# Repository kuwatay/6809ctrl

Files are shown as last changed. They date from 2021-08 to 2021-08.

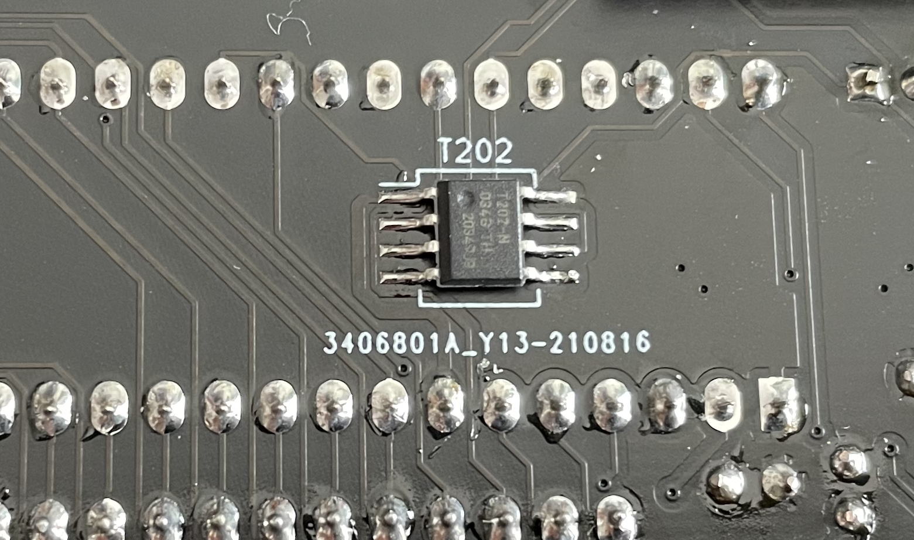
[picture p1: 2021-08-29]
hardware/6809E-CLOCK/clock-gen-t202.jpg

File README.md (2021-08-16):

# 6809ctrl (UNDER DEVELOPMENT)
AVR-based supervisor for a 6809E microcomputer based on z80ctrl https://github.com/jblang/z80ctrl

* Arduino Shield style hardware (6809Ectrl-mega)
* Flexible MIT-licensed firmware inhelited from z80ctrl

# Documentation

## Application

## Hardware note
https://github.com/kuwatay/6809ctrl/tree/main/hardware
## Supervisor sample session

## DMA handling

## MIT license
Permission is hereby granted, free of charge, to any person obtaining a copy of this software and associated documentation files (the "Software"), to deal in the Software without restriction, including without limitation the rights to use, copy, modify, merge, publish, distribute, sublicense, and/or sell copies of the Software, and to permit persons to whom the Software is furnished to do so, subject to the following conditions:

The above copyright notice and this permission notice shall be included in all copies or substantial portions of the Software.

THE SOFTWARE IS PROVIDED "AS IS", WITHOUT WARRANTY OF ANY KIND, EXPRESS OR IMPLIED, INCLUDING BUT NOT LIMITED TO THE WARRANTIES OF MERCHANTABILITY, FITNESS FOR A PARTICULAR PURPOSE AND NONINFRINGEMENT. IN NO EVENT SHALL THE AUTHORS OR COPYRIGHT HOLDERS BE LIABLE FOR ANY CLAIM, DAMAGES OR OTHER LIABILITY, WHETHER IN AN ACTION OF CONTRACT, TORT OR OTHERWISE, ARISING FROM, OUT OF OR IN CONNECTION WITH THE SOFTWARE OR THE USE OR OTHER DEALINGS IN THE SOFTWARE.

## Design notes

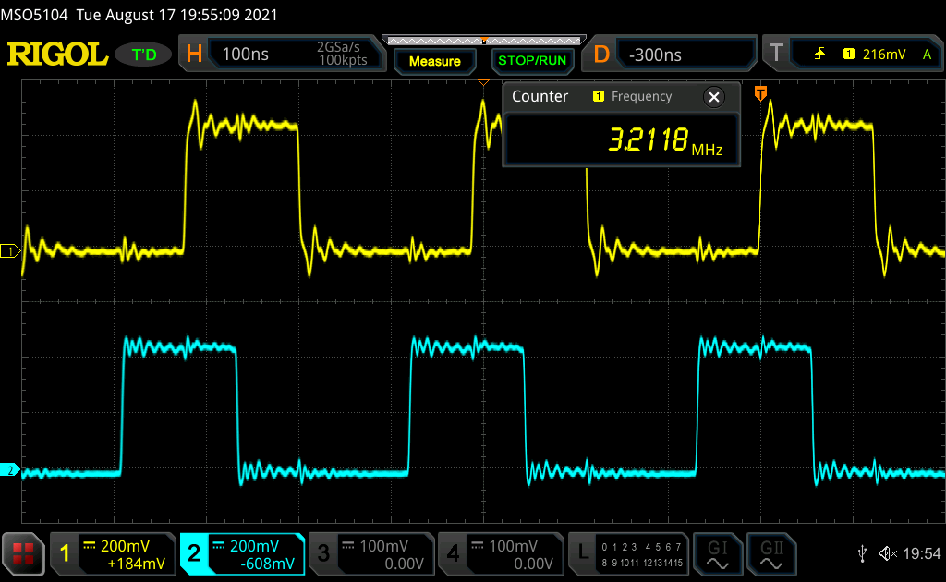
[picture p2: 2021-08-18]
hardware/6809E-CLOCK/3MHz-clock.png

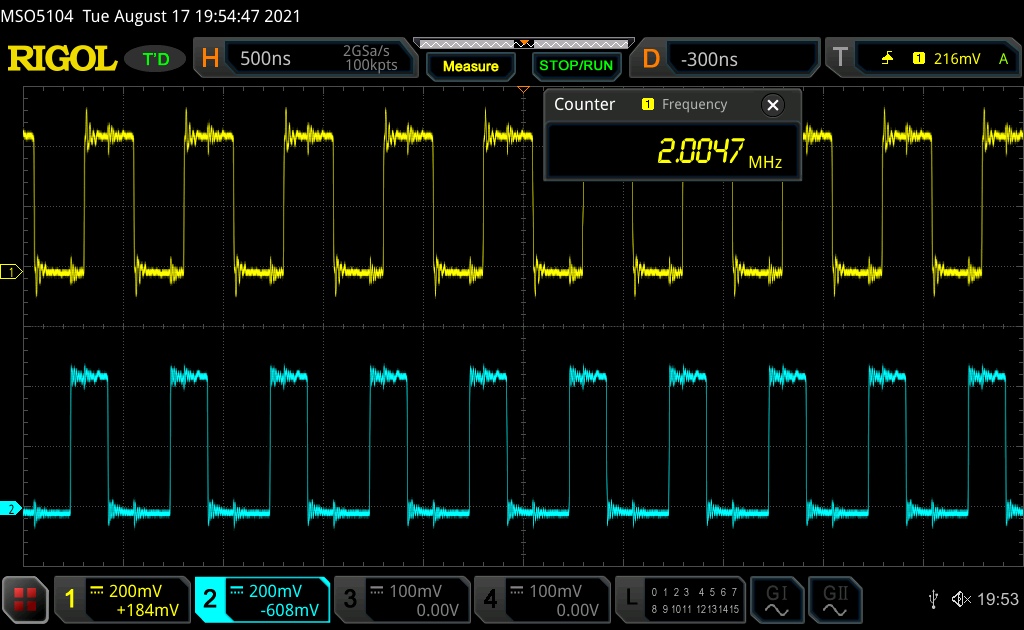
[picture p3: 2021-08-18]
hardware/6809E-CLOCK/2MHz-clock.png

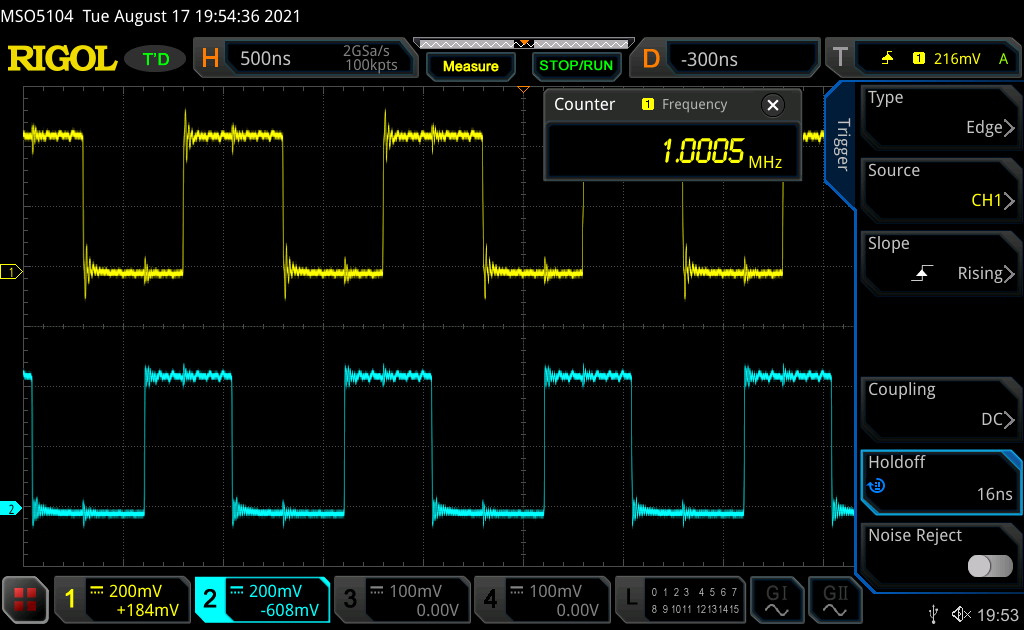
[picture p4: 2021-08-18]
hardware/6809E-CLOCK/1MHz-clock.png

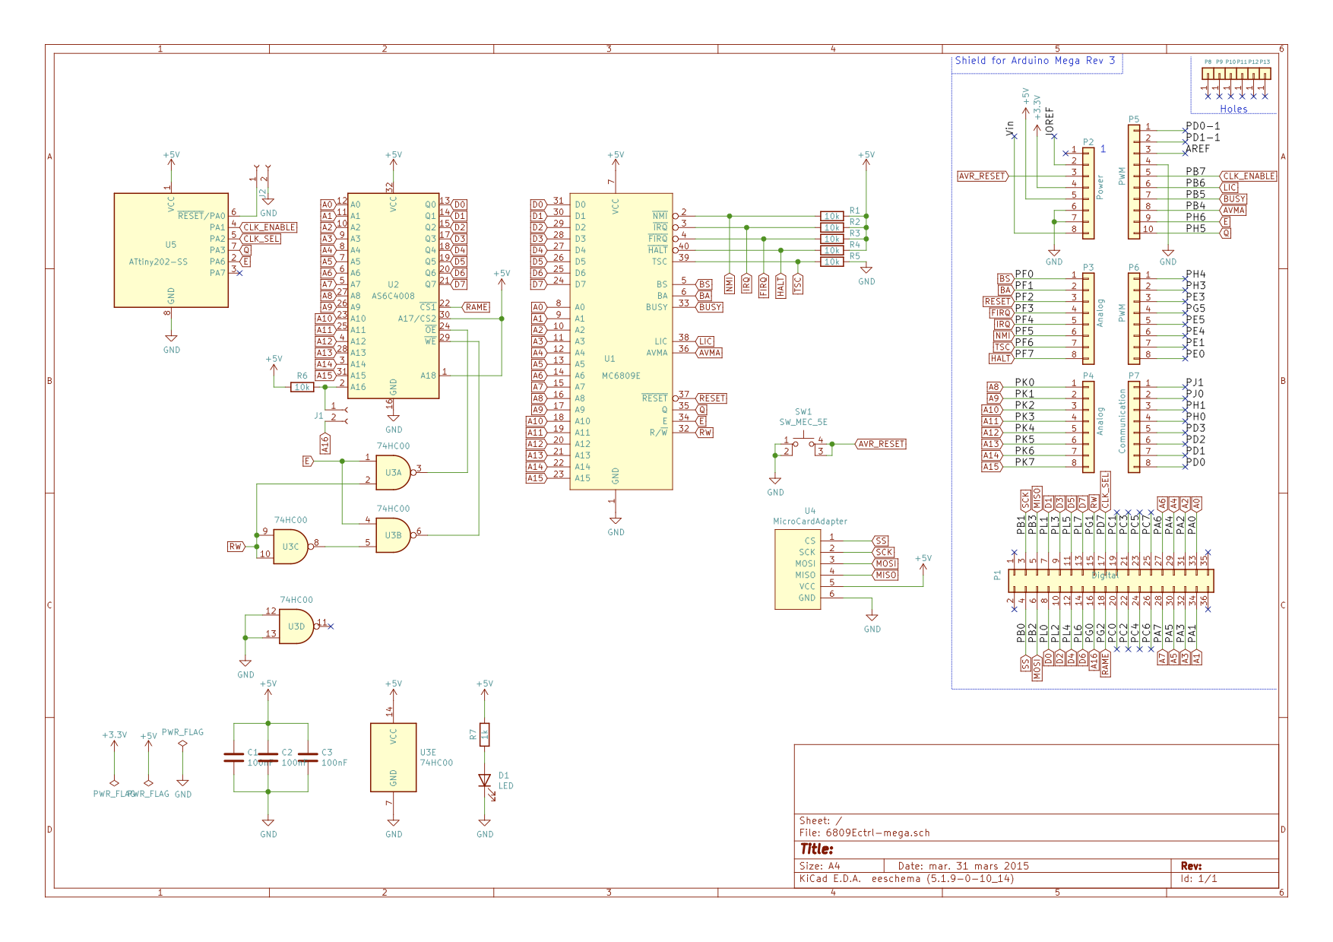
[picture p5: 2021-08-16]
hardware/6809E-mega-schematic.png

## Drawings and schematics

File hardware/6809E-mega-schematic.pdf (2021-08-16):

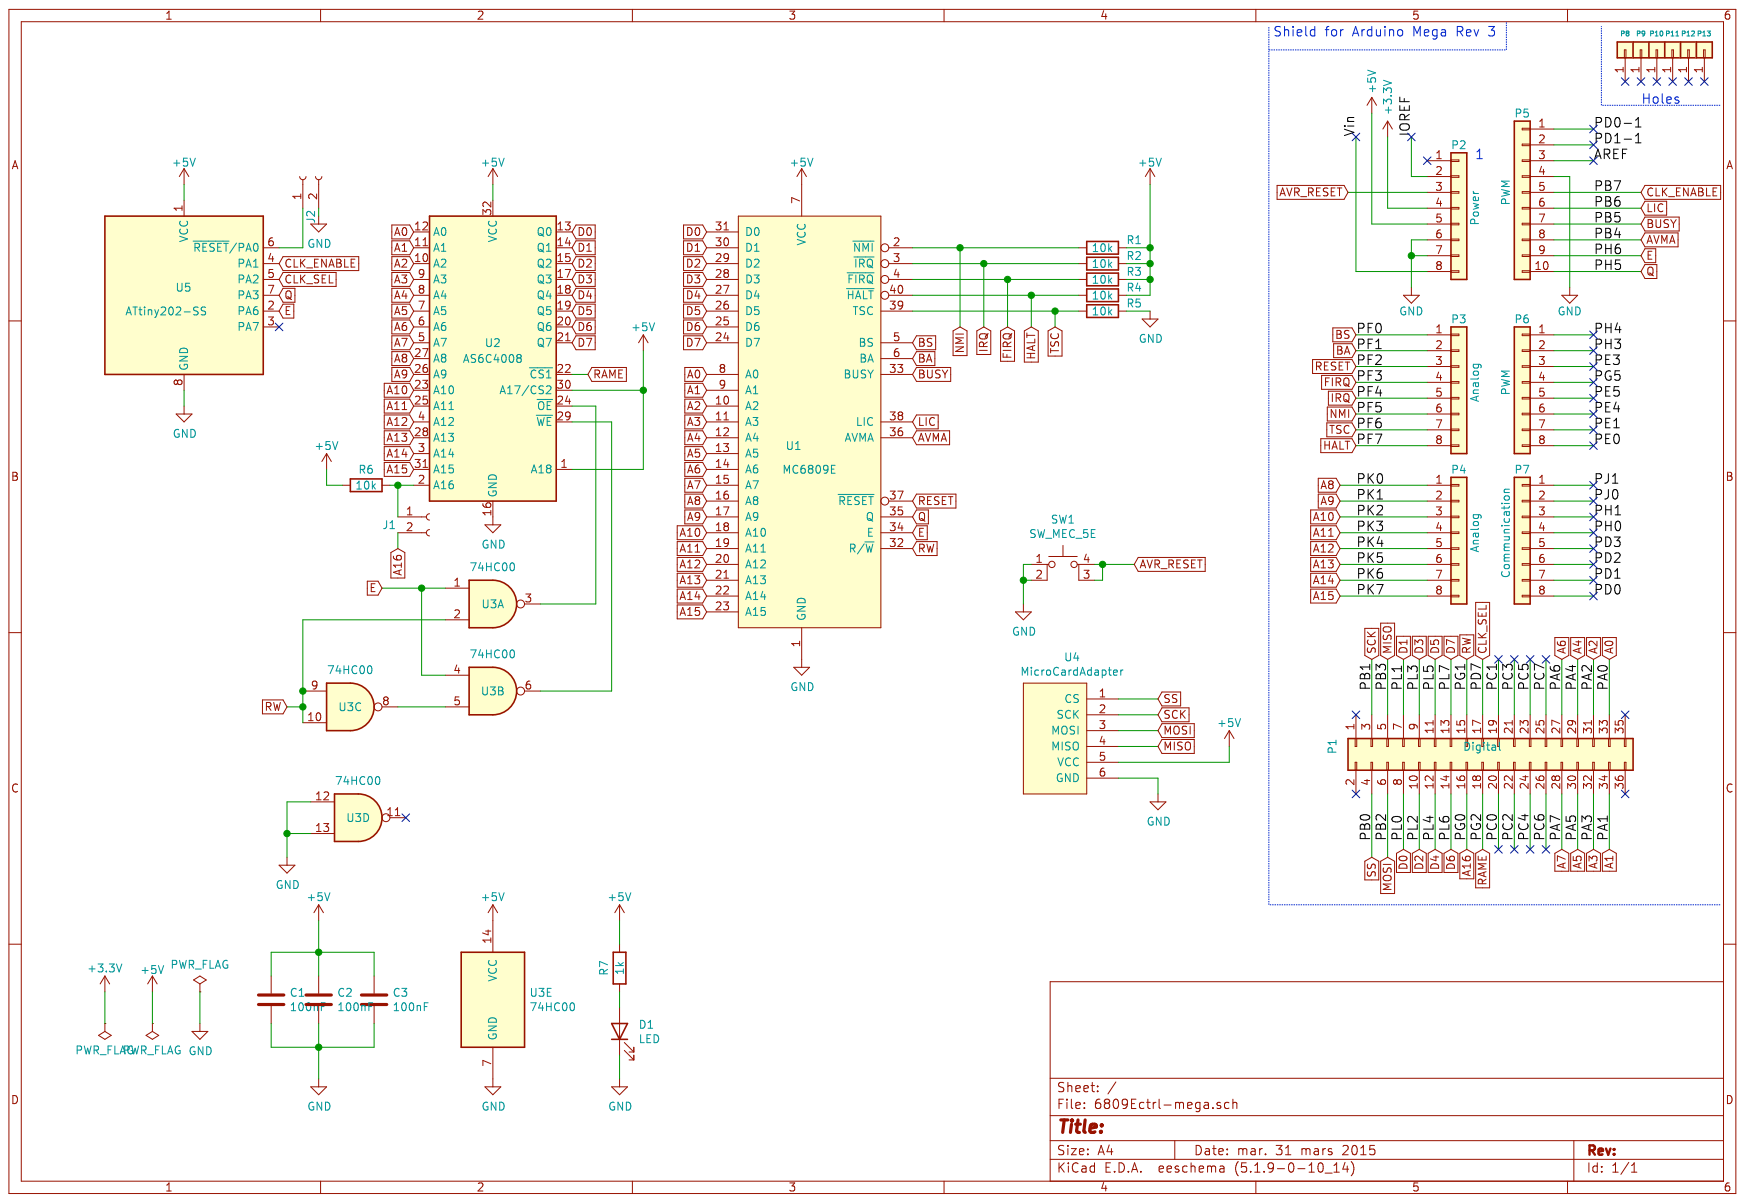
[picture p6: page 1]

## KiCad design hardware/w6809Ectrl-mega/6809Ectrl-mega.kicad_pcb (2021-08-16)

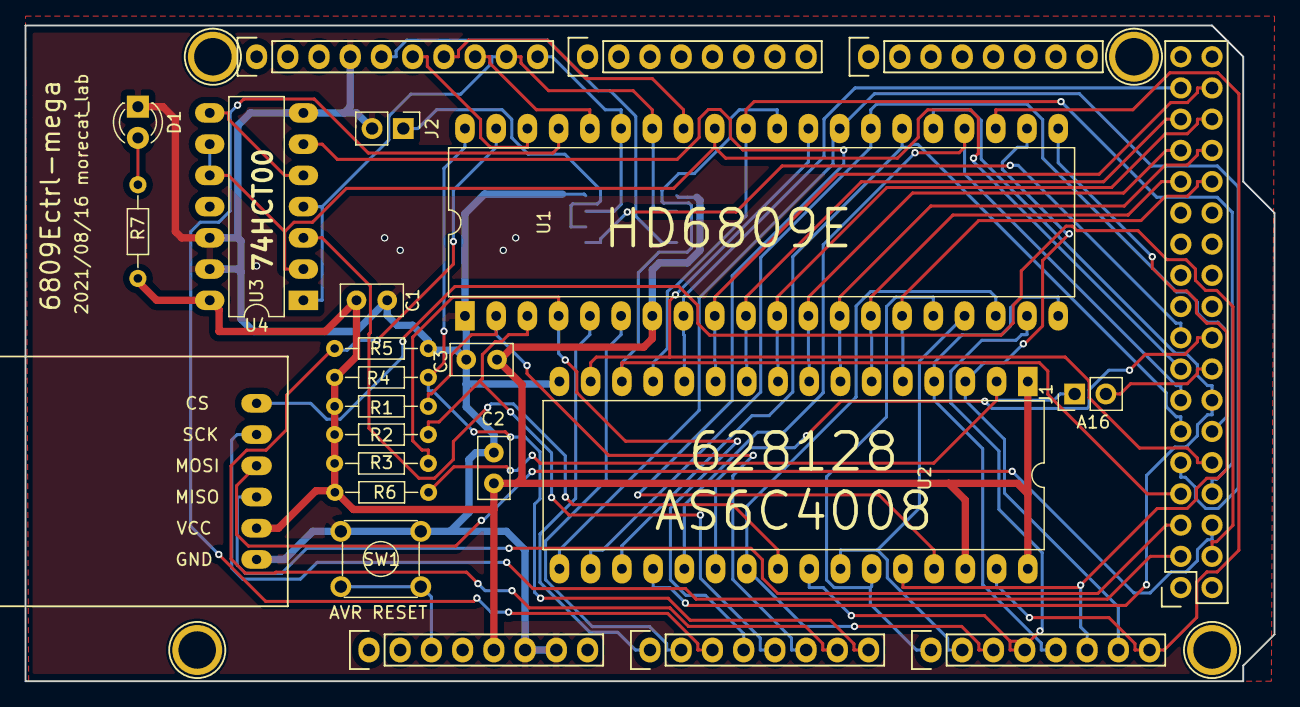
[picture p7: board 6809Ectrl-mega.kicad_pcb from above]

Board: 2 copper layers, 101.6 x 53.3 mm, 30 parts (1 on the bottom side), 55 nets.

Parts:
C1, C2, C3: 100nF; C_Disc_D5.0mm_W2.5mm_P2.50mm
D1: LED; LED_D3.0mm
J1, J2: Conn_01x02_Female; Pin_Header_Straight_1x02_Pitch2.54mm
P1: Digital; Socket_Strip_Arduino_2x18
P2: Power; Socket_Strip_Arduino_1x08
P3, P4: Analog; Socket_Strip_Arduino_1x08
P5: PWM; Socket_Strip_Arduino_1x10
P6: PWM; Socket_Strip_Arduino_1x08
P7: Communication; Socket_Strip_Arduino_1x08
P8, P10, P11, P13: CONN_01X01; Arduino_1pin
R1, R2, R3, R4, R5, R6: 10k; R_Axial_DIN0204_L3.6mm_D1.6mm_P7.62mm_Horizontal
R7: 1k; R_Axial_DIN0204_L3.6mm_D1.6mm_P7.62mm_Horizontal
SW1: SW_MEC_5E; SW_TH_Tactile_Omron_B3F-10xx
T202: ATtiny202-SS; SO-8_5.3x6.2mm_Pitch1.27mm
U1: MC6809E; DIP-40_W15.24mm_LongPads
U2: AS6C4008; DIP-32_W15.24mm_LongPads
U3: 74HC00; DIP-14_W7.62mm_LongPads
U4: MicroCardAdapter; MicroSDCardAdapter

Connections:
+5V: C1.1, C2.1, C3.1, P2.5, R1.1, R2.1, R3.1, R4.1, R6.2, R7.1, T202.1, U1.7, U2.1, U2.30, U2.32, U3.14, U4.5
A0: P1.33, U1.8, U2.12
A1: P1.34, U1.9, U2.11
A2: P1.31, U1.10, U2.10
A3: P1.32, U1.11, U2.9
A4: P1.29, U1.12, U2.8
A5: P1.30, U1.13, U2.7
A6: P1.27, U1.14, U2.6
A7: P1.28, U1.15, U2.5
A8: P4.1, U1.16, U2.27
A9: P4.2, U1.17, U2.26
A10: P4.3, U1.18, U2.23
A11: P4.4, U1.19, U2.25
A12: P4.5, U1.20, U2.4
A13: P4.6, U1.21, U2.28
A14: P4.7, U1.22, U2.3
A15: P4.8, U1.23, U2.31
A16: J1.2, P1.16
AVMA: P5.8, U1.36
AVR_RESET: P2.3, SW1.3, SW1.4
BA: P3.2, U1.6
BS: P3.1, U1.5
BUSY: P5.7, U1.33
CLK_ENABLE: P5.5, T202.4
CLK_SEL: P1.17, T202.5
D0: P1.8, U1.31, U2.13
D1: P1.7, U1.30, U2.14
D2: P1.10, U1.29, U2.15
D3: P1.9, U1.28, U2.17
D4: P1.12, U1.27, U2.18
D5: P1.11, U1.26, U2.19
D6: P1.14, U1.25, U2.20
D7: P1.13, U1.24, U2.21
E: P5.9, T202.2, U1.34, U3.1, U3.4
FIRQ: P3.4, R3.2, U1.4
GND: C1.2, C2.2, C3.2, D1.1, J2.2, P2.6, P2.7, P5.4, R5.1, SW1.1, SW1.2, T202.8, U1.1, U2.16, U3.7, U3.12, U3.13, U4.6
HALT: P3.8, R4.2, U1.40
IRQ: P3.5, R2.2, U1.3
LIC: P5.6, U1.38
MISO: P1.5, U4.4
MOSI: P1.6, U4.3
NMI: P3.6, R1.2, U1.2
unnamed: D1.2, R7.2
unnamed: J1.1, R6.1, U2.2
unnamed: J2.1, T202.6
unnamed: U2.24, U3.3
unnamed: U2.29, U3.6
unnamed: U3.5, U3.8
Q: P5.10, T202.7, U1.35
RAME: P1.18, U2.22
RESET: P3.3, U1.37
RW: P1.15, U1.32, U3.2, U3.9, U3.10
SCK: P1.3, U4.2
SS: P1.4, U4.1
TSC: P3.7, R5.2, U1.39

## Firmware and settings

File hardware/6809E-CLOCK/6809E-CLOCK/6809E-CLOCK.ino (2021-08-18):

///////////////////////////////////////////
// two phased clock generator for 6809E
//
//  Copyright (c) 2021 by Y.Kuwata
///////////////////////////////////////////

// ATtiny202 with 16MHz internal Clock (MegaTinyCore)
// 
// PIN ASSIGN
//
//           +--U--+
//   Vcc 1  -|     |-  8  GND
//   E   2  -|     |-  7  Q
// RESET 3  -|     |-  6  (UPDI)
// SEL1  4  -|     |-  5  SEL2
//           +-----+
//
//   CLOCK SELECTION TABLE
//
//       SEL1   SEL2
// 1MHz   H      H
// 2MHz   L      H
// 3MHz   H      L
// FLOAT  L      L

#include <Logic.h>
#include <util/delay.h>

void setupLogic() {
  Logic0.enable = true;                 // Enable logic block 0
  Logic0.input0 = in::masked;           // mask input0 (NOT Use TCA0 WO0 as input 0)
  Logic0.input1 = in::tca0;             // Use TCA0 WO1 as input 1
  Logic0.input2 = in::tca0;             // Use TCA0 WO2 as input 2
  Logic0.output = out::enable;          // Enable logic block 0 output pin at PA6 (PIN2)
  Logic0.filter = filter::disable;      // delay 2 clock
  Logic0.truth = 0x3c;                  // Set truth table - ex-or 
  Logic0.init();   // Initialize logic block 0
}

#define ENABLE_LOGIC Logic::start()
#define DISABLE_LOGIC Logic::stop()

void setup1M() {
  pinMode(PIN_PA3, OUTPUT);           // PIN 7 for clock (WO0)
  TCA0.SINGLE.PER = 15;  // f = 16 / (1 + 15) = 1MHz 
  TCA0.SINGLE.CMP0 = 7;  // 50% duty 
  TCA0.SINGLE.CMP1 = 3;  // 25% duty 
  TCA0.SINGLE.CMP2 = 11;  // 75% duty   
  TCA0.SINGLE.CTRLA = TCA_SINGLE_ENABLE_bm; //enable the timer with no prescaler
  ENABLE_LOGIC;
}

void setup2M() {
  pinMode(PIN_PA3, OUTPUT);           // PIN 7 for clock (WO0)
  TCA0.SINGLE.PER =  7;  // f = 16 / (1 + 7) = 2MHz 
  TCA0.SINGLE.CMP0 = 3;  // 50% duty 
  TCA0.SINGLE.CMP1 = 1;  // 25% duty 
  TCA0.SINGLE.CMP2 = 5;  // 75% duty   
  TCA0.SINGLE.CTRLA = TCA_SINGLE_ENABLE_bm; //enable the timer with no prescaler
  ENABLE_LOGIC;
}

void setup3M() {
  pinMode(PIN_PA3, OUTPUT);           // PIN 7 for clock (WO0)
  TCA0.SINGLE.PER =  4;  // f = 16 / (1 + 4) =~ 3.2MHz 
  TCA0.SINGLE.CMP0 = 2;  // 50% duty 
  TCA0.SINGLE.CMP1 = 1;  // 25% duty 
  TCA0.SINGLE.CMP2 = 3;  // 75% duty   
  TCA0.SINGLE.CTRLA = TCA_SINGLE_ENABLE_bm; //enable the timer with no prescaler
  ENABLE_LOGIC;
}

void setupFloat() {
  DISABLE_LOGIC;  // stop logic
  pinMode(PIN_PA3, INPUT);
  pinMode(PIN_PA6, INPUT);
}

void setup() {

  pinMode(PIN_PA1, INPUT_PULLUP);     // PIN 4 for input
  pinMode(PIN_PA2, INPUT_PULLUP);     // PIN 5 for input
  pinMode(PIN_PA7, OUTPUT);           // PIN 3 for RESET
  digitalWrite(PIN_PA7, LOW);         // /RESET
  PORTMUX.CTRLC = PORTMUX_TCA00_DEFAULT_gc; //turn off PORTMUX, returning WO0 to PA3

  // set single mode
  TCA0.SPLIT.CTRLA = 0; //disable TCA0 and set divider to 1
  TCA0.SPLIT.CTRLESET = TCA_SPLIT_CMD_RESET_gc | 0x03; //set CMD to RESET, and enable on both pins.
  TCA0.SPLIT.CTRLD = 0; //Split mode now off, CMPn = 0, CNT = 0, PER = 255

  // use single slope pwm mode
  TCA0.SINGLE.CTRLB = (TCA_SINGLE_CMP0EN_bm | TCA_SINGLE_CMP1EN_bm |TCA_SINGLE_CMP2EN_bm |TCA_SINGLE_WGMODE_SINGLESLOPE_gc);

  setupLogic();
  setup1M();
  _delay_ms(600);
  digitalWrite(PIN_PA7, HIGH);   // release RESET

}

static uint8_t mode = 3;
void loop() {
  uint8_t x = digitalRead(PIN_PA2) << 1 | digitalRead(PIN_PA1);
  if (x != mode) {
    switch (x) {
      case 0:
        setupFloat();
        break;
      case 1:
        setup3M();
        break;
      case 2:
        setup2M();
        break;
      case 3:
        setup1M();
        break;
    }
    mode = x;
  }
  _delay_ms(10);
}
